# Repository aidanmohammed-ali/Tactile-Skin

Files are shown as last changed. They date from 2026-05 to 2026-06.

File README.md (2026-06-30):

# Tactile-Skin

This project focuses on creating a thin, flexible tactile skin that measures mechanical pressure, rather than just proximity. This repository contains the firmware and signal processing logic to convert physical deformation and capacitance into usable digital data and the schematics and Gerber files for the requisite hardware.

## Repository Structure

### Firmware
The core software running on the microcontroller, built using PlatformIO. It handles high-speed analog acquisition from the skin matrix and packs it for serial transmission.
* `/src`: Main firmware source files (`.c` & `.cpp`).
* `/include`: Global header files (`.h`).
* `platformio.ini`: The core PlatformIO configuration script.

### Tools (`/tools`)
* `/common`: Shared, hardware-agnostic C++ data engine containing the core signal processing logic and GUI rendering requirements. Folder required to compile both visualiser and raw-streaming.
* `/visualiser`: A high-performance, cross-platform desktop utility built with Raylib. Features include:
  * **Multi-Instance Isolation:** Run multiple parallel instances side-by-side to monitor independent microcontrollers simultaneously.
  * **Dynamic Port Mapping:** Hot-swap hardware link contexts on-the-fly via an integrated UI selector.
  * **Zero-Lag Simulation Mode:** Automated fallback to a high-fidelity Gaussian simulation model when running offline.
  * **Dynamic Profile Loading:** Real-time parameter loading via local `.ini` configuration files to calibrate individual sensor variations dynamically without recompiling the codebase.
* `/raw-streaming`: A utility based on the visualiser for streaming the raw sensor data without any signal processing. Raw data across a specified time frame can be saved in `.csv` format and used for data analysis.

### Hardware (`/hardware`)
* `/fpc`: Flexible Printed Circuit manufacturing files.
  * Complete production-ready Gerber packages.
* `/pcb`: Main rigid Printed Circuit Board design histories.
  * Main interface between the sensor and microcontroller.

## Contribution Guidelines

To keep the project history clean and professional, please follow these conventions:

### Git Commit Prefixes
Use **Conventional Commits**. Start every commit message with one of these:
* **`Docs:`** Documentation changes or code comments (e.g., `Docs: update README`).
* **`Feat:`** New features or logic (e.g., `Feat: implementation of scan loop`).
* **`Fix:`** Bug fixes (e.g., `Fix: corrected index overflow`).
* **`Chore:`** Maintenance tasks, library imports, or project scaffolding (e.g., `Chore: import USB core libraries`).

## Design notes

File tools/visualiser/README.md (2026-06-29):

# Visualiser

A high-performance, cross-platform desktop utility built with C++ and Raylib to map, calibrate, and simulate physical data from the Tactile Skin hardware matrix.

visualiser

## Compilation Guide

### Prerequisites
Before compiling, you must install the native development tools and **Raylib** setup for your operating system.

### Windows (MSYS2 / MinGW-w64)
The most reliable way to compile the C++ Raylib environment on Windows is via the MSYS2 UCRT64 subsystem.

1. Download and install [MSYS2](https://www.msys2.org/).
2. Open the **MSYS2 UCRT64** terminal from the Windows Start menu (do not use the standard MSYS terminal).
3. Update the package database and install the GCC compiler alongside the pre-compiled Raylib package:

   ```bash
   pacman -Syu
   pacman -S mingw-w64-ucrt-x86_64-gcc mingw-w64-ucrt-x86_64-raylib
4. Navigate to the project directory.
5. Compile the program. Windows requires explicitly linking  the underlying OS graphics and media subsystems:

   ```bash
   g++ main.cpp ../common/config.cpp -o visualiser.exe -O2 -Wall -I../common -lraylib -lopengl32 -lgdi32 -lwinmm
6. Run the executable directly from terminal:

   ```bash
   ./visualiser.exe

### Linux (Ubuntu / Debian)
Linux natively supports the POSIX serial architecture and only requires the standard build toolchain.

1. Install the required development packages and Raylib:

   ```bash
   sudo apt update
   sudo apt install build-essential libraylib-dev
   ```
2. Navigate to the project directory and compile:

   ```bash
   g++ main.cpp ../common/config.cpp -o visualiser -O2 -Wall -I../common -lraylib -lGL -lm -lpthread -ldl -lrt -lX11
   ```
3. Run the executable:

   ```bash
   ./visualiser
   ```

### Linux (Fedora / RHEL)
Fedora uses the `dnf`  manager and slightly different package names. But the compilation process is identical to Debian-based systems.

1. Install the GCC compiler suite and Raylib development headers:

   ```bash
   sudo dnf install gcc-c++ raylib-devel
   ```

2. Navigate to the project directory and compile:

   ```bash
   g++ main.cpp ../common/config.cpp -o visualiser -O2 -Wall -I../common -lraylib -lGL -lm -lpthread -ldl -lrt -lX11
   ```
3. Run the executable:

   ```bash
   ./visualiser
   ```

### macOS (Apple Silicon & Intel)
Because macOS is UNIX-based, the application utilises the exact same non-blocking POSIX serial logic as Linux. The easiest way to install dependencies is via Homebrew.

1. Install the Xcode Command Line Tools and Raylib via Homebrew:

   ```bash
   xcode-select --install
   brew install raylib
   ```
2. Navigate to the project directory. macOS requires linking Apple's native rendering frameworks:

   ```bash
   clang++ main.cpp ../common/config.cpp -o visualiser -O2 -Wall -I../common -lraylib -framework CoreVideo -framework IOKit -framework Cocoa -framework OpenGL
   ```
3. Run the executable:

   ```bash
   ./visualiser
   ```

## Hardware Connection & Usage

When connecting the physical Tactile Skin matrix via USB, ensure the correct hardware node is selected from the menu to avoid falling back to Simulation Mode.

* Windows: Open **Device Manager** and expand _Ports_ to find your assigned port (e.g., `COM7`). Select this exact port from the visualiser's menu.
* Linux (Ubuntu/Fedora): The hardware will typically mount to `/dev/ttyACM0` or `/dev/ttyACM1`.
  * _Note: If the application throws an immediate connection error, ensure the user has serial port permissions by running: `sudo usermod -a -G dialout $USER` (requires a logout/login to take effect)._
* macOS: Apple handles the serial devices differently. Look for paths like `/dev/cu.usbmodem` or `/dev/tty.usbmodem`. (This path may need to be manually typed into the codebase if it is not present in the default menu).

## Calibration Wizard

Once the hardware link is live (indicated by the green status bar), clear the sensor and press [C] to Tare. Press [R] at any time to clear the mapping and reset to default.

## Configuration (.ini) Setup

The application features a built-in configuration profile manager. Users can type the specific name or path of an `.ini` file into the UI text entry box and click the Load button to instantly apply different profiles.

If no custom file is specified, the application defaults to the hardcoded values. Configuration files must be stored in the same directory as the visualiser executable. Example `.ini` files can be found in this repository.

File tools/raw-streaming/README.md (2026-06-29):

# Visualiser

A high-performance, cross-platform desktop utility built with C++ and Raylib to display, and simulate physical data from the Tactile Skin hardware matrix.

## Compilation Guide

### Prerequisites
Before compiling, you must install the native development tools and **Raylib** setup for your operating system.

### Windows (MSYS2 / MinGW-w64)
The most reliable way to compile the C++ Raylib environment on Windows is via the MSYS2 UCRT64 subsystem.

1. Download and install [MSYS2](https://www.msys2.org/).
2. Open the **MSYS2 UCRT64** terminal from the Windows Start menu (do not use the standard MSYS terminal).
3. Update the package database and install the GCC compiler alongside the pre-compiled Raylib package:

   ```bash
   pacman -Syu
   pacman -S mingw-w64-ucrt-x86_64-gcc mingw-w64-ucrt-x86_64-raylib
4. Navigate to the project directory.
5. Compile the program. Windows requires explicitly linking  the underlying OS graphics and media subsystems:

   ```bash
   g++ main.cpp -o raw-streaming.exe -O2 -Wall -I../common -lraylib -lopengl32 -lgdi32 -lwinmm
6. Run the executable directly from terminal:

   ```bash
   ./raw-streaming.exe

### Linux (Ubuntu / Debian)
Linux natively supports the POSIX serial architecture and only requires the standard build toolchain.

1. Install the required development packages and Raylib:

   ```bash
   sudo apt update
   sudo apt install build-essential libraylib-dev
   ```
2. Navigate to the project directory and compile:

   ```bash
   g++ main.cpp -o raw-streaming -O2 -Wall -I../common -lraylib -lGL -lm -lpthread -ldl -lrt -lX11
   ```
3. Run the executable:

   ```bash
   ./raw-streaming
   ```

### Linux (Fedora / RHEL)
Fedora uses the `dnf`  manager and slightly different package names. But the compilation process is identical to Debian-based systems.

1. Install the GCC compiler suite and Raylib development headers:

   ```bash
   sudo dnf install gcc-c++ raylib-devel
   ```

2. Navigate to the project directory and compile:

   ```bash
   g++ main.cpp -o raw-streaming -O2 -Wall -I../common -lraylib -lGL -lm -lpthread -ldl -lrt -lX11
   ```
3. Run the executable:

   ```bash
   ./raw-streaming
   ```

### macOS (Apple Silicon & Intel)
Because macOS is UNIX-based, the application utilises the exact same non-blocking POSIX serial logic as Linux. The easiest way to install dependencies is via Homebrew.

1. Install the Xcode Command Line Tools and Raylib via Homebrew:

   ```bash
   xcode-select --install
   brew install raylib
   ```
2. Navigate to the project directory. macOS requires linking Apple's native rendering frameworks:

   ```bash
   clang++ main.cpp -o raw-streaming -O2 -Wall -I../common -lraylib -framework CoreVideo -framework IOKit -framework Cocoa -framework OpenGL
   ```
3. Run the executable:

   ```bash
   ./raw-streaming
   ```

## Hardware Connection & Usage

When connecting the physical Tactile Skin matrix via USB, ensure the correct hardware node is selected from the menu to avoid falling back to Simulation Mode.

* Windows: Open **Device Manager** and expand _Ports_ to find your assigned port (e.g., `COM7`). Select this exact port from the visualiser's menu.
* Linux (Ubuntu/Fedora): The hardware will typically mount to `/dev/ttyACM0` or `/dev/ttyACM1`.
  * _Note: If the application throws an immediate connection error, ensure the user has serial port permissions by running: `sudo usermod -a -G dialout $USER` (requires a logout/login to take effect)._
* macOS: Apple handles the serial devices differently. Look for paths like `/dev/cu.usbmodem` or `/dev/tty.usbmodem`. (This path may need to be manually typed into the codebase if it is not present in the default menu).

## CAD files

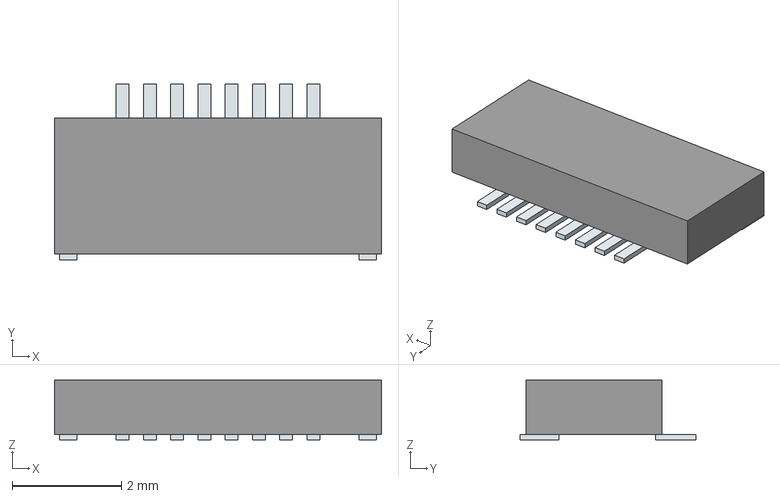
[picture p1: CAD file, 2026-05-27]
hardware/pcb/v1.3/custom_libs/FH19C-8S-0.5SH_10_/3D/FH19C-8S-0.5SH_10_.stp
6.00 x 3.23 x 1.10 mm
Pins

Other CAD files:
hardware/pcb/v1.3/custom_libs/FH19C-8S-0.5SH_10_/Allegro/fh19c8s05sh10.psm
hardware/pcb/v1.3/custom_libs/FH19C-8S-0.5SH_10_/DEHDL/fh19c_8s_0.5sh_10_/chips/chips.prt

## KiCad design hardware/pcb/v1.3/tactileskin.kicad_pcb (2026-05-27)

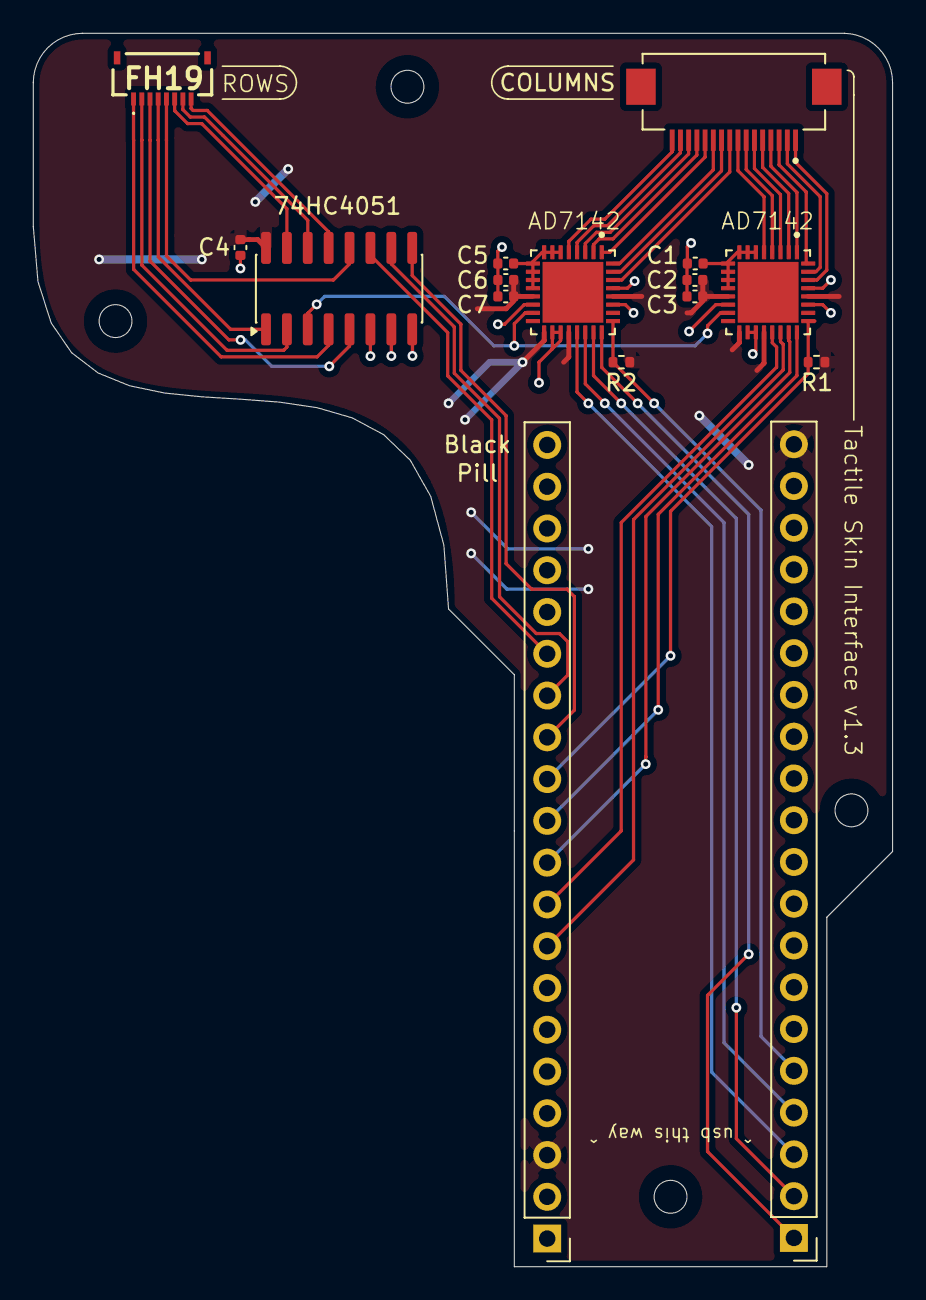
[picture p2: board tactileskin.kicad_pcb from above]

Board: 2 copper layers, 52.3 x 75.0 mm, 16 parts (0 on the bottom side), 43 nets.

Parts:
74HC4051: 74HC4051; SOIC-16_3.9x9.9mm_P1.27mm
AD7142_a1, AD7142_b1: QFN50P500X500X100-33N
Black: Conn_01x20_Pin; PinHeader_1x20_P2.54mm_Vertical
C1, C5: 10n; C_0402_1005Metric
C2, C6: 0.1u; C_0402_1005Metric
C3, C7: 10u; C_0402_1005Metric
C4: 100n; C_0402_1005Metric
COLUMNS: FH12-16S-0.5SH_55_; HIROSE_FH12-16S-0.5SH_55_
FH19: FH19C-8S-0.5SH_10_; FH19C8S05SH10
J_MCU_LEFT1: Conn_01x20_Pin; PinHeader_1x20_P2.54mm_Vertical
R1, R2: 2.2k; R_0402_1005Metric

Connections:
+3.3V: 74HC4051.16 (VCC), AD7142_a1.13 (AVCC), AD7142_a1.17 (DVCC), AD7142_a1.20 (VDRIVE), AD7142_a1.28 (Vref+), AD7142_b1.13 (AVCC), AD7142_b1.17 (DVCC), AD7142_b1.20 (VDRIVE), AD7142_b1.28 (Vref+), Black.3, C2.1, C3.1, C4.1, C6.1, C7.1, J_MCU_LEFT1.20, R1.1, R2.1
+5V: Black.1, J_MCU_LEFT1.18
/A0: 74HC4051.11 (S0), Black.15
/A1: 74HC4051.10 (S1), Black.14
/A2: 74HC4051.9 (S2), Black.13
/A3: AD7142_a1.25 (~INT), Black.12, R1.2
/A4: AD7142_a1.24 (~CS), Black.11
/A5: AD7142_a1.23 (SCLK), Black.10
/A6: AD7142_a1.21 (SDO), Black.9
/A7: AD7142_a1.22 (SDI), Black.8
/A8: AD7142_b1.25 (~INT), J_MCU_LEFT1.5, R2.2
/B12: AD7142_b1.24 (~CS), J_MCU_LEFT1.1
/B13: AD7142_b1.23 (SCLK), J_MCU_LEFT1.2
/B14: AD7142_b1.21 (SDO), J_MCU_LEFT1.3
/B15: AD7142_b1.22 (SDI), J_MCU_LEFT1.4
GND: 74HC4051.6 (~E), 74HC4051.7 (VEE), 74HC4051.8 (GND), AD7142_a1.14 (AGND), AD7142_a1.18 (DGND1), AD7142_a1.19 (DGND2), AD7142_a1.27 (TEST), AD7142_a1.29 (Vref-), AD7142_b1.14 (AGND), AD7142_b1.18 (DGND1), AD7142_b1.19 (DGND2), AD7142_b1.27 (TEST), AD7142_b1.29 (Vref-), Black.2, C1.2, C2.2, C3.2, C4.2, C5.2, C6.2, C7.2, J_MCU_LEFT1.19
unnamed: AD7142_a1.30 (CIN0), COLUMNS.1
unnamed: AD7142_a1.31 (CIN1), COLUMNS.2
unnamed: AD7142_a1.32 (CIN2), COLUMNS.3
unnamed: AD7142_a1.1 (CIN3), COLUMNS.4
unnamed: AD7142_a1.2 (CIN4), COLUMNS.5
unnamed: AD7142_a1.3 (CIN5), COLUMNS.6
unnamed: AD7142_a1.4 (CIN6), COLUMNS.7
unnamed: AD7142_a1.5 (CIN7), COLUMNS.8
unnamed: AD7142_a1.6 (CIN8), AD7142_a1.7 (CIN9), AD7142_a1.8 (CIN10), AD7142_a1.9 (CIN11), AD7142_a1.10 (CIN12), AD7142_a1.11 (CIN13), AD7142_a1.12 (CSHIELD), C1.1
unnamed: 74HC4051.3 (A), AD7142_a1.15 (SRC), AD7142_b1.15 (SRC)
unnamed: AD7142_b1.30 (CIN0), COLUMNS.9
unnamed: AD7142_b1.31 (CIN1), COLUMNS.10
unnamed: AD7142_b1.32 (CIN2), COLUMNS.11
unnamed: AD7142_b1.1 (CIN3), COLUMNS.12
unnamed: AD7142_b1.2 (CIN4), COLUMNS.13
unnamed: AD7142_b1.3 (CIN5), COLUMNS.14
unnamed: AD7142_b1.4 (CIN6), COLUMNS.15
unnamed: AD7142_b1.5 (CIN7), COLUMNS.16
unnamed: AD7142_b1.6 (CIN8), AD7142_b1.7 (CIN9), AD7142_b1.8 (CIN10), AD7142_b1.9 (CIN11), AD7142_b1.10 (CIN12), AD7142_b1.11 (CIN13), AD7142_b1.12 (CSHIELD), C5.1
unnamed: 74HC4051.13 (A0), FH19.8
unnamed: 74HC4051.14 (A1), FH19.7
unnamed: 74HC4051.15 (A2), FH19.6
unnamed: 74HC4051.12 (A3), FH19.5
unnamed: 74HC4051.1 (A4), FH19.4
unnamed: 74HC4051.5 (A5), FH19.3
unnamed: 74HC4051.2 (A6), FH19.2
unnamed: 74HC4051.4 (A7), FH19.1

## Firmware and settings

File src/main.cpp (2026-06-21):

/**
 * @file main.cpp
 * @author Aidan Mohammed-Ali
 * @brief Hardware-specific implementation for tactile skin.
 * * This file acts as the Hardware Driver Layer.
 * @date 2026-04-29
 */

#include <stdio.h>
#include <stdlib.h>
#include <string.h>
#include <stm32f4xx_hal.h>

#define RUN_HARDWARE_TEST 0

extern "C" {
	#include "usbd_core.h"
	#include "usbd_cdc.h"
	
	#include "matrix_scan.h"
	
	extern USBD_HandleTypeDef hUsbDeviceFS;
	extern USBD_DescriptorsTypeDef FS_Desc;
	extern USBD_CDC_ItfTypeDef USBD_Interface_fops_FS;
}

SPI_HandleTypeDef hspi1; // CDC A
SPI_HandleTypeDef hspi2; // CDC B

volatile uint8_t current_column = 0;
volatile uint8_t cdc_a_conversion_complete = 0;
volatile uint8_t cdc_b_conversion_complete = 0;

bool cdc_b_hardware_present = false;

int8_t (*original_st_receive_func)(uint8_t*, uint32_t*) = NULL;

uint16_t sensor_data[128] = {0};

// Payload
#pragma pack(push, 1)
typedef struct {
	uint8_t magic_header[4];
	uint16_t matrix_data[128];
} serialised_packet_t;
#pragma pack(pop)

static serialised_packet_t usb_tx_packet;

/**
 * @brief Structure to pair an AD7142 register address with its configuration value.
 */
typedef struct {
	uint16_t reg_addr;
	uint16_t reg_val;
} ad7142_reg_config_t;

// Hardware initialisation
void SystemClock_Config(void);
void MX_GPIO_Init(void);
void MX_SPI1_Init(void);
void MX_SPI2_Init(void);
void AD7142_Init(void);
void Clear_CDC_Interrupts(void);

/**
 * @brief Bridge function to set physical GPIO states.
 * @param gpio_pin Number of the pin being used.
 * @param state Value being applied to the pin.
 */
extern "C" void set_gpio_state(uint8_t gpio_pin, uint8_t state) {
	GPIO_PinState s = (state) ? GPIO_PIN_SET : GPIO_PIN_RESET;
	
	if (gpio_pin == 0) HAL_GPIO_WritePin(GPIOA, GPIO_PIN_0, s);
	if (gpio_pin == 1) HAL_GPIO_WritePin(GPIOA, GPIO_PIN_1, s);
	if (gpio_pin == 2) HAL_GPIO_WritePin(GPIOA, GPIO_PIN_2, s);
}

/**
 * @brief Helper function to write a 16-bit value to a specific AD7142 register.
 * @param hspi Pointer to the SPI handler structure.
 * @param cs_port Pointer to the GPIO port instance for Chip Select.
 * @param cs_pin GPIO Pin number for Chip Select.
 * @param reg_addr Target register address on the AD7142.
 * @param data_val 16-bit data value to write to the register.
 */
void AD7142_Write_Reg(SPI_HandleTypeDef *hspi, GPIO_TypeDef *cs_port, uint16_t cs_pin, uint16_t reg_addr, uint16_t data_val) {
	alignas(2) uint16_t tx_buf[2];
	tx_buf[0] = (uint16_t)(0xE000 | (reg_addr & 0x03FF));
	tx_buf[1] = data_val;
	
	HAL_GPIO_WritePin(cs_port, cs_pin, GPIO_PIN_RESET);
	HAL_SPI_Transmit(hspi, (uint8_t*)tx_buf, 2, 10);
	HAL_GPIO_WritePin(cs_port, cs_pin, GPIO_PIN_SET);
}

/**
 * @brief Helper function to read a 16-bit value from a specific AD7142 register.
 * @param hspi Pointer to the SPI handler structure.
 * @param cs_port Pointer to the GPIO port instance for Chip Select.
 * @param cs_pin GPIO Pin number for Chip Select.
 * @param reg_addr Target register address on the AD7142.
 * @retval Value read from the AD7142 register.
 */
uint16_t AD7142_Read_Reg(SPI_HandleTypeDef *hspi, GPIO_TypeDef *cs_port, uint16_t cs_pin, uint16_t reg_addr) {
	alignas(2) uint16_t tx_buf[2];
	alignas(2) uint16_t rx_buf[2] = {0, 0};
	tx_buf[0] = (uint16_t)(0xE400 | (reg_addr & 0x03FF));
	tx_buf[1] = 0x0000;
	
	HAL_GPIO_WritePin(cs_port, cs_pin, GPIO_PIN_RESET);
	for(volatile int d = 0; d < 50; ++d);
	HAL_SPI_TransmitReceive(hspi, (uint8_t*)tx_buf, (uint8_t*)rx_buf, 2, 10);
	HAL_GPIO_WritePin(cs_port, cs_pin, GPIO_PIN_SET);
	
	return rx_buf[1];
}

/**
 * @brief Bridge function to read two sensors at once.
 * @param val_a Pointer to location of first value to be read.
 * @param val_b Pointer to location of second value to be read.
 */
extern "C" void get_sensor_pair(uint16_t *val_a, uint16_t *val_b) {
	alignas(2) uint16_t tx_buf[2];
	alignas(2) uint16_t rx_buf_a[2] = {0, 0};
	alignas(2) uint16_t rx_buf_b[2] = {0, 0};
	
	tx_buf[0] = (uint16_t)(0xE400 | ((0x00B + current_column) & 0x03FF));
	tx_buf[1] = 0x0000;
	
	// CDC A
	HAL_GPIO_WritePin(GPIOA, GPIO_PIN_4, GPIO_PIN_RESET);
	for(volatile int d=0; d<50; d++);
	HAL_SPI_TransmitReceive(&hspi1, (uint8_t*)tx_buf, (uint8_t*)rx_buf_a, 2, 10);
	HAL_GPIO_WritePin(GPIOA, GPIO_PIN_4, GPIO_PIN_SET);
	*val_a = rx_buf_a[1];
	
	// CDC B (Only if it exists)
	if (cdc_b_hardware_present) {
		HAL_GPIO_WritePin(GPIOB, GPIO_PIN_12, GPIO_PIN_RESET);
		for(volatile int d=0; d<50; d++);
		HAL_SPI_TransmitReceive(&hspi2, (uint8_t*)tx_buf, (uint8_t*)rx_buf_b, 2, 10);
		HAL_GPIO_WritePin(GPIOB, GPIO_PIN_12, GPIO_PIN_SET);
		*val_b = rx_buf_b[1];
	} else {
		*val_b = 0;
	}
}

/**
 * @brief Set the active CDC column channel for the matrix scanner.
 * @param col_addr The column index requested by the library.
 */
extern "C" void set_cdc_channel(uint8_t col_addr) {
	current_column = col_addr;
}

/**
 * @brief Initialise the hardware DWT cycle counter for precision delays.
 */
void DWT_Delay_Init(void) {
	CoreDebug->DEMCR |= CoreDebug_DEMCR_TRCENA_Msk;
	DWT->CYCCNT = 0;
	DWT->CTRL |= DWT_CTRL_CYCCNTENA_Msk;
}

/**
 * @brief Microsecond delay block.
 * @param us Number of microseconds to pause.
 */
extern "C" void delay_us(uint16_t us) {
	uint32_t start_tick = DWT->CYCCNT;
	
	uint32_t target_ticks = (uint32_t)us * (SystemCoreClock / 1000000);
	while ((DWT->CYCCNT - start_tick) < target_ticks);
}

/**
 * @brief Tells the AD7142 to perform exactly one scan of the current row.
 */
void trigger_AD7142(void) {
	cdc_a_conversion_complete = 0;
	cdc_b_conversion_complete = 0;
	
	AD7142_Write_Reg(&hspi1, GPIOA, GPIO_PIN_4, 0x000, 0x0170);
	
	if (cdc_b_hardware_present) {
		AD7142_Write_Reg(&hspi2, GPIOB, GPIO_PIN_12, 0x000, 0x0170);
	}
}

/**
 * @brief Halts the MCU until the AD7142 physical interrupt pin fires.
 */
void wait_for_AD7142(void) {
	uint32_t timeout = 20000;
	
	while (cdc_a_conversion_complete == 0 && timeout > 0) {
		if (HAL_GPIO_ReadPin(GPIOA, GPIO_PIN_3) == GPIO_PIN_RESET) {
			break;
		}
		timeout--;
	}
	
	if (cdc_b_hardware_present) {
		timeout = 20000;
		while (cdc_b_conversion_complete == 0 && timeout > 0) {
			if (HAL_GPIO_ReadPin(GPIOA, GPIO_PIN_8) == GPIO_PIN_RESET){
				break;
			}
			timeout--;
		}
	}
}

/**
 * @brief Inverts the row scanning to match the visualiser mapping.
 */
void set_mux_row_inverted(uint8_t addr) {
	set_mux_row(7 - addr);
}

int main(void) {
	// Initialise STM32
	HAL_Init();
	HAL_Delay(1000);
	SystemClock_Config();	
	DWT_Delay_Init();

#if RUN_HARDWARE_TEST == 1
	/**
	 * @brief Hardware bit-bang configuration diagnostics segment.
	 * @note Leave untouched.
	 */
	// Setup pins
	__HAL_RCC_GPIOA_CLK_ENABLE();
	__HAL_RCC_GPIOB_CLK_ENABLE();
	
	// SPI1
	GPIO_InitTypeDef GPIO_InitStruct = {0};
	GPIO_InitStruct.Pin = GPIO_PIN_4 | GPIO_PIN_5 | GPIO_PIN_7; // CS, SCK, MOSI
	GPIO_InitStruct.Mode = GPIO_MODE_OUTPUT_PP;
	GPIO_InitStruct.Pull = GPIO_NOPULL;
	GPIO_InitStruct.Speed = GPIO_SPEED_FREQ_VERY_HIGH;
	HAL_GPIO_Init(GPIOA, &GPIO_InitStruct);
	
	GPIO_InitStruct.Pin = GPIO_PIN_6; // MISO
	GPIO_InitStruct.Mode = GPIO_MODE_INPUT;
	GPIO_InitStruct.Pull = GPIO_NOPULL;
	HAL_GPIO_Init(GPIOA, &GPIO_InitStruct);
	
	// SPI2
	GPIO_InitStruct.Pin = GPIO_PIN_12 | GPIO_PIN_13 | GPIO_PIN_15; // CS, SCK, MOSI
	GPIO_InitStruct.Mode = GPIO_MODE_OUTPUT_PP;
	GPIO_InitStruct.Pull = GPIO_NOPULL;
	GPIO_InitStruct.Speed = GPIO_SPEED_FREQ_VERY_HIGH;
	HAL_GPIO_Init(GPIOB, &GPIO_InitStruct);
	
	GPIO_InitStruct.Pin = GPIO_PIN_14; // MISO
	GPIO_InitStruct.Mode = GPIO_MODE_INPUT;
	GPIO_InitStruct.Pull = GPIO_NOPULL;
	HAL_GPIO_Init(GPIOB, &GPIO_InitStruct);
	
	// Set default states
	HAL_GPIO_WritePin(GPIOA, GPIO_PIN_4 | GPIO_PIN_5, GPIO_PIN_SET);
	HAL_GPIO_WritePin(GPIOB, GPIO_PIN_12 | GPIO_PIN_13, GPIO_PIN_SET);
	
	// Start USB manually
	USBD_Init(&hUsbDeviceFS, &FS_Desc, 0);
	USBD_RegisterClass(&hUsbDeviceFS, USBD_CDC_CLASS);
	USBD_CDC_RegisterInterface(&hUsbDeviceFS, &USBD_Interface_fops_FS);
	USBD_Start(&hUsbDeviceFS);
	HAL_Delay(1000);
	
	while (1) {
		uint16_t tx_cmd = 0xE417;
		uint16_t id_a = 0;
		uint16_t id_b = 0;
		
		// Manually read CDC A
		HAL_GPIO_WritePin(GPIOA, GPIO_PIN_4, GPIO_PIN_RESET);
		delay_us(10);
		for (int i = 15; i >= 0; --i) {
			HAL_GPIO_WritePin(GPIOA, GPIO_PIN_5, GPIO_PIN_RESET);
			HAL_GPIO_WritePin(GPIOA, GPIO_PIN_7, (tx_cmd & (1 << i)) ? GPIO_PIN_SET : GPIO_PIN_RESET);
			delay_us(10);
			HAL_GPIO_WritePin(GPIOA, GPIO_PIN_5, GPIO_PIN_SET);
			delay_us(10);
		}
		for (int i = 15; i >= 0; --i) {
			HAL_GPIO_WritePin(GPIOA, GPIO_PIN_5, GPIO_PIN_RESET);
			delay_us(10);
			HAL_GPIO_WritePin(GPIOA, GPIO_PIN_5, GPIO_PIN_SET);
			if (HAL_GPIO_ReadPin(GPIOA, GPIO_PIN_6) == GPIO_PIN_SET) { id_a |= (1 << i); }
			delay_us(10);
		}
		HAL_GPIO_WritePin(GPIOA, GPIO_PIN_4, GPIO_PIN_SET);
		
		// Manually read CDC B
		HAL_GPIO_WritePin(GPIOB, GPIO_PIN_12, GPIO_PIN_RESET);
		delay_us(10);
		for (int i = 15; i >= 0; --i) {
			HAL_GPIO_WritePin(GPIOB, GPIO_PIN_13, GPIO_PIN_RESET);
			HAL_GPIO_WritePin(GPIOB, GPIO_PIN_15, (tx_cmd & (1 << i)) ? GPIO_PIN_SET : GPIO_PIN_RESET);
			delay_us(10);
			HAL_GPIO_WritePin(GPIOB, GPIO_PIN_13, GPIO_PIN_SET);
			delay_us(10);
		}
		for (int i = 15; i >= 0; --i) {
			HAL_GPIO_WritePin(GPIOB, GPIO_PIN_13, GPIO_PIN_RESET);
			delay_us(10);
			HAL_GPIO_WritePin(GPIOB, GPIO_PIN_13, GPIO_PIN_SET);
			if (HAL_GPIO_ReadPin(GPIOB, GPIO_PIN_14) == GPIO_PIN_SET) { id_b |= (1 << i); }
			delay_us(10);
		}
		HAL_GPIO_WritePin(GPIOB, GPIO_PIN_12, GPIO_PIN_SET);
		
		// Print result
		char report[256];
		int len = snprintf(report, sizeof(report), 
							"\r\n--- BIT-BANG HARDWARE DIAGNOSTIC ---\r\n"
							"CDC A (PA4/5/6/7)        ID: 0x%04X\r\n"
							"CDC B (PB12/13/14/15)    ID: 0x%04X\r\n"
							"------------------------------------\r\n",
							id_a, id_b);
		
		USBD_CDC_HandleTypeDef *hcdc_main = (USBD_CDC_HandleTypeDef*)hUsbDeviceFS.pClassData;
		
		if (hcdc_main != NULL && hcdc_main->TxState == 0) {
			USBD_CDC_SetTxBuffer(&hUsbDeviceFS, (uint8_t*)report, len);
			USBD_CDC_TransmitPacket(&hUsbDeviceFS);
		}
		
		HAL_Delay(1000);
	}
#else
	// Initialise peripheral ports
	MX_GPIO_Init();
	MX_SPI1_Init();
	MX_SPI2_Init();
	AD7142_Init();
	
	// Initialise and start the native USB CDC Virtual COM Port stack
	USBD_Init(&hUsbDeviceFS, &FS_Desc, 0);
	USBD_RegisterClass(&hUsbDeviceFS, USBD_CDC_CLASS);
	USBD_CDC_RegisterInterface(&hUsbDeviceFS, &USBD_Interface_fops_FS);
	USBD_Start(&hUsbDeviceFS);
	
	// Configure tactile geometry
	matrix_config_t skin_config = {};
	skin_config.num_row_addr_pins = 3;
	skin_config.num_col_addr_pins = 4;
	skin_config.num_row_en_pins = 0;
	skin_config.num_col_en_pins = 0;
	
	skin_config.row_addr_pins[0] = 0;
	skin_config.row_addr_pins[1] = 1;
	skin_config.row_addr_pins[2] = 2;
	
	skin_config.set_row_func = set_mux_row_inverted;
	skin_config.set_col_func = set_cdc_channel;
	
	skin_config.trigger_scan_func = trigger_AD7142;
	skin_config.wait_ready_func = wait_for_AD7142;
	skin_config.clear_interrupt_func = Clear_CDC_Interrupts;
	
	skin_config.settle_time_us = 20;
	
	matrix_init(&skin_config);
	
	// Clear initial startup triggers
	Clear_CDC_Interrupts();
	cdc_a_conversion_complete = 0;
	cdc_b_conversion_complete = 0;
	
	usb_tx_packet.magic_header[0] = 0xDE;
	usb_tx_packet.magic_header[1] = 0xAD;
	usb_tx_packet.magic_header[2] = 0xBE;
	usb_tx_packet.magic_header[3] = 0xEF;
	
	while (1) {
		matrix_scan_parallel(sensor_data);
		
		static uint32_t last_print_time = 0;
		if (HAL_GetTick() - last_print_time > 50) {		
			USBD_CDC_HandleTypeDef *hcdc_main = (USBD_CDC_HandleTypeDef*)hUsbDeviceFS.pClassData;
			
			if (hcdc_main != NULL && hcdc_main->TxState == 0) {
				last_print_time = HAL_GetTick();
				
				memcpy(usb_tx_packet.matrix_data, sensor_data, 256);
				
				USBD_CDC_SetTxBuffer(&hUsbDeviceFS, (uint8_t*)&usb_tx_packet, sizeof(usb_tx_packet));
				USBD_CDC_TransmitPacket(&hUsbDeviceFS);
			}
		}
	}
#endif
}

/**
 * @brief Configure the system clock source and bus dividers.
 */
void SystemClock_Config(void) {
	RCC_OscInitTypeDef RCC_OscInitStruct = {0};
	RCC_ClkInitTypeDef RCC_ClkInitStruct = {0};
	
	// Enable power interface clock
	__HAL_RCC_PWR_CLK_ENABLE();
	__HAL_PWR_VOLTAGESCALING_CONFIG(PWR_REGULATOR_VOLTAGE_SCALE1);
	
	// Set physical 25MHz external crystal as clock source
	RCC_OscInitStruct.OscillatorType = RCC_OSCILLATORTYPE_HSE;
	RCC_OscInitStruct.HSEState = RCC_HSE_ON;
	
	// Enable PLL
	RCC_OscInitStruct.PLL.PLLState = RCC_PLL_ON;
	RCC_OscInitStruct.PLL.PLLSource = RCC_PLLSOURCE_HSE;	
	
	// Multiplication math (96MHz clock)
	RCC_OscInitStruct.PLL.PLLM = 25;
	RCC_OscInitStruct.PLL.PLLN = 192;
	RCC_OscInitStruct.PLL.PLLP = RCC_PLLP_DIV2;
	RCC_OscInitStruct.PLL.PLLQ = 4;
	
	// Physically apply configuration
	if (HAL_RCC_OscConfig(&RCC_OscInitStruct) != HAL_OK) {
		while(1);
	}
	
	// Configure clock
	RCC_ClkInitStruct.ClockType = RCC_CLOCKTYPE_HCLK | RCC_CLOCKTYPE_SYSCLK |
									RCC_CLOCKTYPE_PCLK1 | RCC_CLOCKTYPE_PCLK2;
	RCC_ClkInitStruct.SYSCLKSource = RCC_SYSCLKSOURCE_PLLCLK;
	
	// Set dividers
	RCC_ClkInitStruct.AHBCLKDivider = RCC_SYSCLK_DIV1;	
	RCC_ClkInitStruct.APB1CLKDivider = RCC_HCLK_DIV2;
	RCC_ClkInitStruct.APB2CLKDivider = RCC_HCLK_DIV1;
	
	// Physically apply configuration
	if (HAL_RCC_ClockConfig(&RCC_ClkInitStruct, FLASH_LATENCY_3) != HAL_OK) {
		while(1);
	}
}

/**
 * @brief Initialise GPIO pins.
 */
void MX_GPIO_Init(void) {
	GPIO_InitTypeDef GPIO_InitStruct = {0};
	
	// Enable internal clocks for GPIOA and GPIOB
	__HAL_RCC_GPIOA_CLK_ENABLE();
	__HAL_RCC_GPIOB_CLK_ENABLE();
	
	// Set default starting states for MUX
	HAL_GPIO_WritePin(GPIOA, GPIO_PIN_0 | GPIO_PIN_1 | GPIO_PIN_2, GPIO_PIN_RESET);
	
	GPIO_InitStruct.Pin = GPIO_PIN_0 | GPIO_PIN_1 | GPIO_PIN_2;
	GPIO_InitStruct.Mode = GPIO_MODE_OUTPUT_PP;
	GPIO_InitStruct.Pull = GPIO_NOPULL;
	GPIO_InitStruct.Speed = GPIO_SPEED_FREQ_LOW;
	
	// Physically apply configuration
	HAL_GPIO_Init(GPIOA, &GPIO_InitStruct);
	
	// Set default starting states for CS (SPI1)
	HAL_GPIO_WritePin(GPIOA, GPIO_PIN_4, GPIO_PIN_SET);
	
	GPIO_InitStruct.Pin = GPIO_PIN_4;
	GPIO_InitStruct.Mode = GPIO_MODE_OUTPUT_PP;
	GPIO_InitStruct.Pull = GPIO_NOPULL;
	GPIO_InitStruct.Speed = GPIO_SPEED_FREQ_LOW;
	
	// Physically apply configuration
	HAL_GPIO_Init(GPIOA, &GPIO_InitStruct);
	
	// Set default starting states for CS (SPI2)
	HAL_GPIO_WritePin(GPIOB, GPIO_PIN_12, GPIO_PIN_SET);
	
	GPIO_InitStruct.Pin = GPIO_PIN_12;
	GPIO_InitStruct.Mode = GPIO_MODE_OUTPUT_PP;
	GPIO_InitStruct.Pull = GPIO_NOPULL;
	GPIO_InitStruct.Speed = GPIO_SPEED_FREQ_LOW;
	
	// Physically apply configuration
	HAL_GPIO_Init(GPIOB, &GPIO_InitStruct);
	
	// Configure INT
	GPIO_InitStruct.Pin = GPIO_PIN_3 | GPIO_PIN_8;
	GPIO_InitStruct.Mode = GPIO_MODE_IT_FALLING;
	GPIO_InitStruct.Pull = GPIO_NOPULL;
	
	// Physically apply configuration
	HAL_GPIO_Init(GPIOA, &GPIO_InitStruct);
	
	// Configure SPI1 hardware
	GPIO_InitStruct.Pin = GPIO_PIN_5 | GPIO_PIN_6 | GPIO_PIN_7;
	GPIO_InitStruct.Mode = GPIO_MODE_AF_PP;
	GPIO_InitStruct.Pull = GPIO_NOPULL;
	GPIO_InitStruct.Speed = GPIO_SPEED_FREQ_VERY_HIGH;
	GPIO_InitStruct.Alternate = GPIO_AF5_SPI1;
	
	// Physically apply configuration
	HAL_GPIO_Init(GPIOA, &GPIO_InitStruct);
	
	// Configure SPI2 hardware
	GPIO_InitStruct.Pin = GPIO_PIN_13 | GPIO_PIN_14 | GPIO_PIN_15;
	GPIO_InitStruct.Mode = GPIO_MODE_AF_PP;
	GPIO_InitStruct.Pull = GPIO_NOPULL;
	GPIO_InitStruct.Speed = GPIO_SPEED_FREQ_VERY_HIGH;
	GPIO_InitStruct.Alternate = GPIO_AF5_SPI2;
	
	// Physically apply configuration
	HAL_GPIO_Init(GPIOB, &GPIO_InitStruct);
	
	// Listen to interrupt channel
	HAL_NVIC_SetPriority(EXTI3_IRQn, 5, 0);
	HAL_NVIC_EnableIRQ(EXTI3_IRQn);
	
	HAL_NVIC_SetPriority(EXTI9_5_IRQn, 5, 0);
	HAL_NVIC_EnableIRQ(EXTI9_5_IRQn);
}

/**
 * @brief Initialise SPI1 for CDC1.
 */
void MX_SPI1_Init(void) {
	__HAL_RCC_SPI1_CLK_ENABLE();
	
	hspi1.Instance = SPI1;
	
	// Configuration for SPI
	hspi1.Init.Mode = SPI_MODE_MASTER;
	hspi1.Init.Direction = SPI_DIRECTION_2LINES;
	hspi1.Init.DataSize = SPI_DATASIZE_16BIT;
	hspi1.Init.CLKPolarity = SPI_POLARITY_HIGH;
	hspi1.Init.CLKPhase = SPI_PHASE_2EDGE;
	hspi1.Init.NSS = SPI_NSS_SOFT;
	
	// Set speed limit
	hspi1.Init.BaudRatePrescaler = SPI_BAUDRATEPRESCALER_16;
	
	// Physically apply configuration
	if (HAL_SPI_Init(&hspi1) != HAL_OK) {
		while(1);
	}
}

/**
 * @brief Initialise SPI2 for CDC2.
 */
void MX_SPI2_Init(void) {
	__HAL_RCC_SPI2_CLK_ENABLE();
	
	hspi2.Instance = SPI2;
	
	// Configuration for SPI
	hspi2.Init.Mode = SPI_MODE_MASTER;
	hspi2.Init.Direction = SPI_DIRECTION_2LINES;
	hspi2.Init.DataSize = SPI_DATASIZE_16BIT;
	hspi2.Init.CLKPolarity = SPI_POLARITY_HIGH;
	hspi2.Init.CLKPhase = SPI_PHASE_2EDGE;
	hspi2.Init.NSS = SPI_NSS_SOFT;
	
	// Set speed limit
	hspi2.Init.BaudRatePrescaler = SPI_BAUDRATEPRESCALER_16;
	
	// Physically apply configuration
	if (HAL_SPI_Init(&hspi2) != HAL_OK) {
		while(1);
	}
}

/**
 * @brief Initialise the AD7142.
 */
void AD7142_Init(void) {
	// Bank 1
	ad7142_reg_config_t bank1_table[] = {
		{0x000, 0x0170}, // PWR_CONTROL
		{0x001, 0x0000}, // STAGE_CAL_EN
		{0x002, 0x0FF0}, // AMB_COMP_CTRL0 (default)
		{0x003, 0x0140}, // AMB_COMP_CTRL1 (default)
		{0x004, 0xFFFF}, // AMB_COMP_CTRL2 (default)
		{0x005, 0x0000}, // STAGE_LOW_INT_EN (default)
		{0x006, 0x0000}, // STAGE_HIGH_INT_EN (default)
		{0x007, 0x0080}  // STAGE_COMPLETE_INT_EN
	};
	
	const int num_registers = sizeof(bank1_table) / sizeof(bank1_table[0]);
	
	// Initialise CDC1
	for (int i = 0; i < num_registers; ++i) {
		AD7142_Write_Reg(&hspi1, GPIOA, GPIO_PIN_4, bank1_table[i].reg_addr, bank1_table[i].reg_val);
	}
	
	// Probe CDC2
	uint16_t cdc_b_id = AD7142_Read_Reg(&hspi2, GPIOB, GPIO_PIN_12, 0x017);
	
	if (cdc_b_id != 0x0000 && cdc_b_id != 0xFFFF) {
		cdc_b_hardware_present = true;
	}
	
	for (int i = 0; i < num_registers; ++i) {
		if (cdc_b_hardware_present) {
			AD7142_Write_Reg(&hspi2, GPIOB, GPIO_PIN_12, bank1_table[i].reg_addr, bank1_table[i].reg_val);
		}
	}
	
	// Bank 2
	uint16_t used_reg_vals[] = {
		0x0001, // STAGEx_CONNECTION[6:0]
		0x4000, // STAGEx_CONNECTION[13:7]
		0x0C00, // STAGEx_AFE_OFFSET
		0x2424, // STAGEx_SENSITIVITY
		0x0F00, // STAGEx_OFFSET_LOW
		0x0F00, // STAGEx_OFFSET_HIGH
		0x07D0, // STAGEx_OFFSET_HIGH_CLAMP
		0x07D0  // STAGEx_OFFSET_LOW_CLAMP
	};
	
	uint16_t unused_reg_vals[] = {
		0x3FFF, // STAGEx_CONNECTION[6:0]
		0xFFFF, // STAGEx_CONNECTION[13:7]
		0x0000, // STAGEx_AFE_OFFSET
		0x0000, // STAGEx_SENSITIVITY
		0x0000, // STAGEx_OFFSET_LOW
		0x0000, // STAGEx_OFFSET_HIGH
		0x0000, // STAGEx_OFFSET_HIGH_CLAMP
		0x0000  // STAGEx_OFFSET_LOW_CLAMP
	};
	
	int stage = 0;
	uint16_t val;
	uint16_t val1;
	uint16_t val2;
	for (uint16_t addr = 0x080; addr < 0x0E0; ) {
		for (uint16_t i = 0; i < 8; ++i) {
			if (stage < 8) {
				switch (i) {
					case 0:
						val = 0x3FFF ^ (used_reg_vals[0] << (2 * stage));
						val = 0x3FFF & val;
						break;
						
					case 1:
						val = 0x3FFF ^ (used_reg_vals[1] >> (2 * stage));
						val = 0x3FFE | val;
						val = 0x3FFF & val;
						break;
						
					case 2:
						val = used_reg_vals[i];
					case 3:						
					case 4:
					case 5:
					case 6:
					case 7:
						val = used_reg_vals[i];
						break;
				}
				
				if (i == 2) {
					val1 = val;
					val2 = val;
				} else {
					val1 = val;
					val2 = val;
				}

				AD7142_Write_Reg(&hspi1, GPIOA, GPIO_PIN_4, addr, val1);
				
				if (cdc_b_hardware_present) {
					AD7142_Write_Reg(&hspi2, GPIOB, GPIO_PIN_12, addr, val2);
				}
			} else {
				AD7142_Write_Reg(&hspi1, GPIOA, GPIO_PIN_4, addr, unused_reg_vals[i]);
				
				if (cdc_b_hardware_present) {
					AD7142_Write_Reg(&hspi2, GPIOB, GPIO_PIN_12, addr, unused_reg_vals[i]);
				}
			}
			addr++;
		}
		stage++;
	}
}

/**
 * @brief Reads the completion status register on both CDCs to clear.
 */
void Clear_CDC_Interrupts(void) {
	uint16_t status_a = AD7142_Read_Reg(&hspi1, GPIOA, GPIO_PIN_4, 0x00A);
		
	(void)status_a;
	
	if (cdc_b_hardware_present) {
		uint16_t status_b = AD7142_Read_Reg(&hspi2, GPIOB, GPIO_PIN_12, 0x00A);
		(void)status_b;
	}
}

/**
 * @brief System tick timer heartbeat.
 */
extern "C" void SysTick_Handler(void) {
	HAL_IncTick();
}

/**
 * @brief Hardware Interrupt Vector for EXTI Line 3.
 */
extern "C" void EXTI3_IRQHandler(void) {
	HAL_GPIO_EXTI_IRQHandler(GPIO_PIN_3);
}

/**
 * @brief Hardware Interrupt Vector for EXTI Lines 5 to 9.
 */
extern "C" void EXTI9_5_IRQHandler(void) {
	HAL_GPIO_EXTI_IRQHandler(GPIO_PIN_8);
}

/**
 * @brief STM32 External Interrupt Callback hook.
 * @param Interrupt GPIO Pin.
 */
void HAL_GPIO_EXTI_Callback(uint16_t GPIO_Pin) {
	if (GPIO_Pin == GPIO_PIN_3) {
		cdc_a_conversion_complete = 1;
	}
	if (GPIO_Pin == GPIO_PIN_8) {
		cdc_b_conversion_complete = 1;
	}
}

/**
 * @brief Hardware Interrupt Vector for the USB On-The-Go Full Speed peripheral channel.
 */
extern "C" {
	extern PCD_HandleTypeDef hpcd_USB_OTG_FS;
	
	void OTG_FS_IRQHandler(void) {
		HAL_PCD_IRQHandler(&hpcd_USB_OTG_FS);
	}
}

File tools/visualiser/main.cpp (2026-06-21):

/**
 * @file main.cpp
 * @author Aidan Mohammed-Ali
 * @brief Visualisation tool.
 * * This file takes the sensor outputs and displays it.
 * @date 2026-05-23
 */

#define RAYGUI_IMPLEMENTATION
#include "raygui.h"

#include <iostream>
#include <cstdint>
#include <vector>
#include <cmath>
#include <cstring>
#include "raylib.h"
#include "processor.hpp"

// Cross-Platform OS Serial Communication
#if defined(_WIN32)
	#ifndef WIN32_LEAN_AND_MEAN
		#define WIN32_LEAN_AND_MEAN // Exclude unneeded legacy Windows headers
	#endif
	#define NOGDI
	#define NOUSER
	#include <windows.h>
#else
	#include <unistd.h>
	#include <fcntl.h>
	#include <termios.h>
	#include <sys/ioctl.h>
#endif

// Geometry configuration 
const int ROWS = 8;
const int COLS = 16;
const int CELL_SIZE = 95;
const int WINDOW_WIDTH = COLS * CELL_SIZE;
const int WINDOW_HEIGHT = ROWS * CELL_SIZE;
const int BAR_HEIGHT = 60;
const int RIGHT_MARGIN = 25;
const int TEXT_Y = 19;
const int STATUS_TEXT_SIZE = 18;

// Calibration step tracker
enum CalibrationWizardStep {
	STEP_READY = 0,
	STEP_WAITING_LOW,
	STEP_WAITING_MID,
	STEP_WAITING_HIGH,
	STEP_COMPLETE
};

CalibrationWizardStep wizard_step = STEP_READY;

// Firmware data structure
#pragma pack(push, 1)
typedef struct {
	uint8_t magic_header[4];
	uint16_t channels[128];
} TactileFrame;
#pragma pack(pop)

// Cross-Platform Serial Handlers
#if defined(_WIN32)
	typedef HANDLE SerialHandle;
	const SerialHandle INVALID_SERIAL = INVALID_HANDLE_VALUE;
#else
	typedef int SerialHandle;
	const SerialHandle INVALID_SERIAL = -1;
#endif

/**
 * @brief Establishes a raw cross-platform connection to the specified hardware serial interface.
 * @param portName The system file descriptor path
 * @retval A functional native system hook, or INVALID_SERIAL if initialisation fails.
 */
SerialHandle OpenSerialPort(const char *portName) {
#if defined(_WIN32)
	SerialHandle handle = CreateFileA(portName, GENERIC_READ | GENERIC_WRITE,
										0, nullptr, OPEN_EXISTING, 0, nullptr);
	if (handle == INVALID_HANDLE_VALUE) {
		return INVALID_SERIAL;
	}
	
	DCB dcbSerialParams = {0};
	dcbSerialParams.DCBlength = sizeof(dcbSerialParams);
	if (!GetCommState(handle, &dcbSerialParams)) {
		CloseHandle(handle);
		return INVALID_SERIAL;
	}
	
	dcbSerialParams.BaudRate = CBR_115200;
	dcbSerialParams.ByteSize = 8;
	dcbSerialParams.StopBits = ONESTOPBIT;
	dcbSerialParams.Parity = NOPARITY;
	
	if (!SetCommState(handle, &dcbSerialParams)) {
		CloseHandle(handle);
		return INVALID_SERIAL;
	}
	
	COMMTIMEOUTS timeouts = {0};
	timeouts.ReadIntervalTimeout = MAXWORD;
	timeouts.ReadTotalTimeoutConstant = 0;
	timeouts.ReadTotalTimeoutMultiplier = 0;
    timeouts.WriteTotalTimeoutConstant = 50;
    timeouts.WriteTotalTimeoutMultiplier = 10;
    
    if (!SetCommTimeouts(handle, &timeouts)) {
        CloseHandle(handle);
        return INVALID_SERIAL;
    }
	
	return handle;
#else
	SerialHandle handle = open(portName, O_RDONLY | O_NOCTTY | O_NDELAY);
	if (handle == -1) {
		return INVALID_SERIAL;
	}
	
	fcntl(handle, F_SETFL, 0);
	
	struct termios tty;
	if (tcgetattr(handle, &tty) != 0) {
		close(handle);
		return INVALID_SERIAL;
	}
	
	cfsetispeed(&tty, B115200);
	tty.c_cflag = (tty.c_cflag & ~CSIZE) | CS8;
	tty.c_iflag &= ~(IGNBRK | BRKINT | PARMRK | ISTRIP | INLCR | IGNCR | ICRNL | IXON);
	tty.c_lflag &= ~(ECHO | ECHONL | ICANON | ISIG | IEXTEN);
	tty.c_oflag &= ~OPOST;
	
	tty.c_cc[VMIN] = 0;
	tty.c_cc[VTIME] = 1;
	
	tty.c_cflag |= (CLOCAL | CREAD);
	
	if (tcsetattr(handle, TCSANOW, &tty) != 0) {
		close(handle);
		return INVALID_SERIAL;
	}
	return handle;
#endif
}

/**
 * @brief Read a complete, raw binary data packet from the active serial interface.
 * @param handle The active operating system serial connection handle.
 * @param frame A reference to the target stucture where incoming sensor values are stored.
 * @retval true If a complete 260-byte frame was successfully synchronised and read without corruption
 * * false If the stream timed out, threw an error, or the buffer was empty.
 */
bool ReadSerialFrame(SerialHandle handle, TactileFrame &frame) {
	if (handle == INVALID_SERIAL) {
		return false;
	}
	
	const uint32_t TOTAL_PACKET_SIZE = sizeof(TactileFrame);
	
#if defined(_WIN32)
	DWORD errors;
	COMSTAT status;	
	ClearCommError(handle, &errors, &status);
	
	if (status.cbInQue < TOTAL_PACKET_SIZE) {
		return false;
	}
#else
	int bytesAvailable = 0;
	
	if (ioctl(handle, FIONREAD, &bytesAvailable) < 0 ||
				bytesAvailable < static_cast<int>(TOTAL_PACKET_SIZE)) {
		return false;
	}
#endif

	uint8_t match_buffer[4] = { 0 };
	
	while (true) {
#if defined(_WIN32)
		DWORD bytesRead;
		if (!ReadFile(handle, &match_buffer[0], 1, &bytesRead, nullptr) || bytesRead != 1) {
			return false;
		}
#else
		ssize_t bytesRead = read(handle, &match_buffer[0], 1);
		if (bytesRead != 1) {
			return false;
		}
#endif

		if (match_buffer[0] == 0xDE) {
#if defined(_WIN32)
			if (!ReadFile(handle, &match_buffer[1], 3, &bytesRead, nullptr) || bytesRead != 3) {
				continue;
			}
#else
			bytesRead = read(handle, &match_buffer[1], 3);
			if (bytesRead != 3) {
				continue;
			}
#endif
			if (match_buffer[1] == 0xAD && match_buffer[2] == 0xBE && match_buffer[3] == 0xEF) {
				std::memcpy(frame.magic_header, match_buffer, 4);
				
				uint8_t *data_destination = reinterpret_cast<uint8_t*>(frame.channels);
				uint32_t bytes_remaining = 256;
				
				while (bytes_remaining > 0) {
#if defined(_WIN32)
					if (!ReadFile(handle, data_destination, bytes_remaining, &bytesRead, nullptr) ||
						bytesRead <= 0) {
							return false;
					}
#else
					bytesRead = read(handle, data_destination, bytes_remaining);
					if (bytesRead <= 0) {
						return false;
					}
#endif
					bytes_remaining -= bytesRead;
					data_destination += bytesRead;
				}
				return true;
			}
		}
	}
	return false;
}

/**
 * @brief Sends a single byte command down the active serial interface.
 * @param handle The active operating system serial connection handle.
 * @param cmd The 8-bit command to transmit.
 * @retval true If the byte was successfully sent without corruption
 * * false Otherwise.
 */
bool WriteSerialByte(SerialHandle handle, uint8_t cmd) {
#if defined(_WIN32)
	DWORD bytesWritten;
	if (WriteFile(handle, &cmd, 1, &bytesWritten, nullptr)) {
		return (bytesWritten == 1);
	}
	return false;
#else
	ssize_t bytesWritten = write(handle, &cmd, 1);
	return (bytesWritten == 1);
#endif
}
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

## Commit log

2026-04-29 Fix: typo in main.cpp
    [main.cpp]
2026-05-01 Feat: addition of signal processing with baseline calibration and noise thresholding
2026-05-05 Fix: refactoring matrix_scan logic and fix pointer initialisation bug
    [matrix_scan.c]
2026-05-14 Merge pull request #2 from ummo-n/pcb
    Feat: addition of Interface PCB v1
    [cdcmux.kicad_sch, connectors.kicad_sch, mcu.kicad_sch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]
2026-05-14 Feat: addition of quadratic calibration using Cramer's rule for tactile processing
2026-05-14 Feat: migration to STM32 and PlatformIO
2026-05-17 Fix: adjusted fpc connector spacing and minor routing errors
    [cdcmux.kicad_sch, connectors.kicad_sch, mcu.kicad_sch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]
2026-05-17 Docs: clearer labeling v1.0 and v1.1
    [cdcmux.kicad_sch, connectors.kicad_sch, mcu.kicad_sch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]
2026-05-17 Feat: add FPC and Gerber folder with EasyEDA designed Gerber Files for FPC and adapters
2026-05-18 Fix: changed devboard orientation
    [cdcmux.kicad_sch, connectors.kicad_sch, mcu.kicad_sch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]
2026-05-18 Feat: migration to STM32 for main loop and integration of processing pipeline
2026-05-20 Feat: implementation of calibration handling and interrupt handling
2026-05-21 Docs: updated platformio.ini to use default framework layout
2026-05-23 Fix: resolved USB CDC middleware and low-level link layer bindings
    [main.cpp]
2026-05-25 Feat: implementation of multi-point hardware calibration wizard
2026-05-27 Merge pull request #9 from ummo-n/pcb-versions
    Feat: added mounting holes and a different 8-pin connector
    [EDI2CAP.CFG, FH19C-8S-0.5SH_10_.SchLib, FH19C-8S-0.5SH_10_.stp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]
2026-05-27 Feat: addition of support for dual-CDC interrupts
2026-05-29 Fix: resolved compiler errors and COM Port selection errors for Windows
    [main.cpp]
2026-05-29 Fix: resolved stuttering on Linux
    [main.cpp]
2026-05-31 Chore: reorganised directory structure
    [EDI2CAP.CFG, FH19C-8S-0.5SH_10_.SchLib, FH19C-8S-0.5SH_10_.stp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]
2026-06-03 Fix: corrected matrix scan hardware timing and MUX addressing
    [matrix_scan.c]
2026-06-03 Fix: correction of SPI logic, interrupt handling and hardware timing
    [main.cpp]
2026-06-03 Fix: removal of troubleshooting artifact
    [matrix_scan.c]
2026-06-05 Fix: corrections to the SPI communication logic and pin assignments
    [main.cpp]
2026-06-05 Feat: implementation of 5-sample median filtering and 2D spatial smoothing
2026-06-09 Fix: addition of delay for scanning logic
    [main.cpp, matrix_scan.c]
2026-06-09 Fix: correction to operations order for parallel scan
    [matrix_scan.c]
2026-06-09 Chore: tuning values for filtering
2026-06-10 Feat: implementation of interrupt logic
2026-06-10 Feat: additional signal processing to reduce noise and random fluctuation
    [processor.hpp]
2026-06-13 Feat: addition of trimming moving average filter for signal processing
2026-06-13 Feat: addition of .ini configuration files for sensor1 and sensor2
2026-06-14 Fix: corrected size error for GuiComboBox
    [main.cpp]
2026-06-15 Fix: corrected variable name in visualiser main.cpp
    [main.cpp]
